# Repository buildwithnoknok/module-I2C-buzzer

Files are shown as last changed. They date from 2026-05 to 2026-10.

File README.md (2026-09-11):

# noknok Buzzer

A compact I²C‑controlled buzzer module for the noknok ecosystem.  
Designed for audio feedback, alerts, melodies, and UI interaction in modular builds.

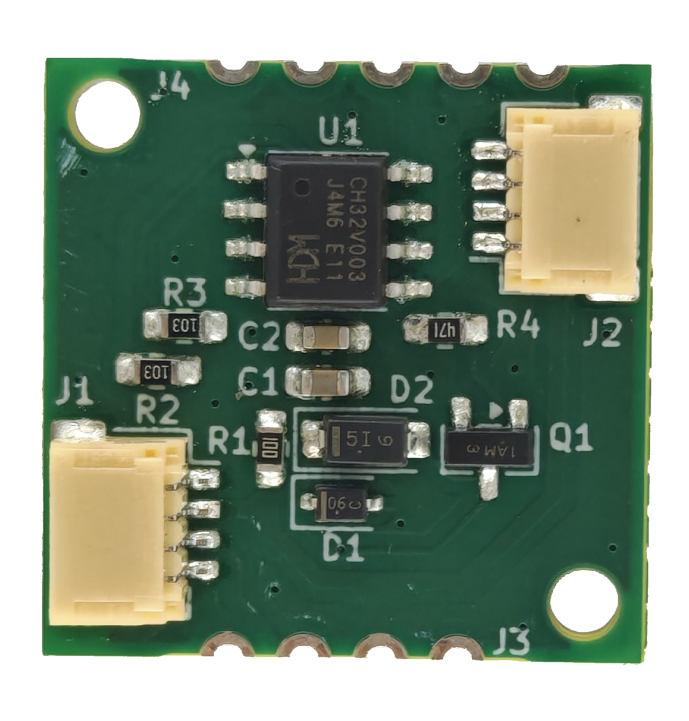
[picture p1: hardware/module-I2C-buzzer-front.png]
Buzzer Module Front

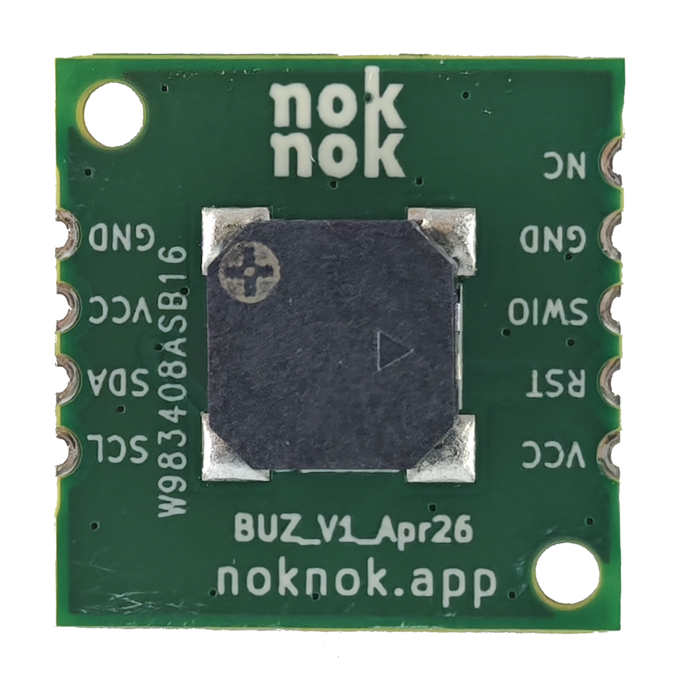
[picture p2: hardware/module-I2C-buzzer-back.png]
Buzzer Module Back


> **Visual concept:** see [`docs/noknok-buzzer-concept.md`](docs/noknok-buzzer-concept.md) for the protocol and architecture diagram (Markdown + SVG, renders right here on GitHub). A styled interactive version is in [`docs/noknok-buzzer-concept.html`](docs/noknok-buzzer-concept.html) (open in a browser).

---

## Overview

The Buzzer Module uses a **CH32V003J4M6** microcontroller to drive an **MLT‑8530** magnetic buzzer via PWM through an MMBT3904 NPN transistor. It connects to the Raspberry Pi Pico (Conductor) over the standard noknok **JST SH 4‑pin I²C connector**.

The Conductor sends a short command — a frequency, duration, and volume, or just a tune ID — and the module handles everything else independently. The Pico is free to do other things while the buzzer plays.

---

## Features

- Dynamic I²C address via noknok enumeration protocol (no hardcoded address)
- CH32V003J4M6 microcontroller (RISC‑V, 48 MHz, 16 KB flash)
- Drives MLT‑8530 magnetic buzzer via PWM
- **Fire and forget** — all timing is handled on‑module
- **Volume control** (0–100%, maps to PWM duty cycle)
- **5 preloaded tunes** stored in flash (Nokia, Happy Birthday, Beep OK/Error, Startup Chime)
- Immediate interrupt — any new command stops whatever is playing
- 3.3V operation via noknok I²C connector
- Compact 20×20 mm PCB

---

## How It Works

```
Your Python code (Pico)          JST SH 4-pin           Buzzer Module (CH32V003)
────────────────────────         ────────────           ────────────────────────
                                  GND ────────
buzzer.play(440, 2.0)  ──────►   3.3V ───────  ──────►  receives 5 bytes
                                  SDA ─ data ─          sets PWM to 440 Hz
                                  SCL ─ clk  ─          starts 2s countdown
                                                         ← ACK (Pico moves on)
                                                         ... 2 seconds pass ...
                                                         timer fires → silence
```

The Pico sends **3–5 bytes** and returns immediately. The CH32V003 handles all timing internally using a hardware timer. No blocking, no waiting.

---

## I²C Protocol

**I²C address:** assigned dynamically at boot — see [Enumeration](#enumeration).

### Commands (Pico → Buzzer)

| Bytes | Command | Description |
|---|---|---|
| `0x00` | **STOP** | Silence immediately |
| `0x01` `fH` `fL` `dur` `vol` | **PLAY NOTE** | Play a tone |
| `0x02` `id` | **PLAY TUNE** | Play a preloaded tune |
| `0xB0` | **ENTER BOOTLOADER** | Reset into the I²C bootloader for an over‑the‑wire firmware update (see [Firmware](#firmware)) |
| `0xB1` | **GET VERSION** | Standard noknok command — the next read returns 4 version bytes (see below) |

**PLAY NOTE fields:**

| Field | Size | Description |
|---|---|---|
| `fH` + `fL` | 2 bytes | Frequency in Hz, big‑endian (e.g. 440 Hz = `0x01 0xB8`) |
| `dur` | 1 byte | Duration in 100 ms units (1 = 100 ms, 10 = 1 s, 0 = play forever) |
| `vol` | 1 byte | Volume 0–100 |

### Status read (Pico ← Buzzer)

Read 1 byte from the module address:

| Value | Meaning |
|---|---|
| `0x01` | Currently playing |
| `0x00` | Idle |

### Version read (Pico ← Buzzer)

`GET_VERSION` (`0xB1`) is a **noknok ecosystem-standard** command (the `0xB0`–`0xBF` range is reserved for standard commands across every module). Write `0xB1`, then read **4 bytes**:

| Byte | Field | Meaning |
|---|---|---|
| 0 | `PROTOCOL_VERSION` | noknok protocol/API version the module speaks (`0x01`) |
| 1 | `FW_MAJOR` | Firmware major (`3`) |
| 2 | `FW_MINOR` | Firmware minor (`3`) |
| 3 | `FW_PATCH` | Firmware patch (`0`) |

Lets the Conductor compare the installed version against the version required by the product manifest. **→ Full spec:** [Ecosystem / software / readme.md §5](https://github.com/buildwithnoknok/Ecosystem/blob/main/software/readme.md#5-standard-system-commands)

---

## Preloaded Tunes

Tunes are stored as `const` arrays in the CH32V003's flash memory. Zero RAM cost.

| ID | Name | Notes |
|----|---|---|
| `0x01` | Nokia Tune | 13 notes |
| `0x02` | Happy Birthday | 28 notes |
| `0x03` | Beep OK | Rising double beep |
| `0x04` | Beep Error | Low double buzz |
| `0x05` | Startup Chime | Rising 4‑note arpeggio (plays on every boot) |

---

## Enumeration

The module uses the standard noknok dynamic enumeration protocol — no hardcoded I²C address. At boot it plays the startup chime while counting a UID-derived backoff delay, then joins the bus at `0x7F` for address assignment by the Conductor.

**→ Full protocol spec:** [Ecosystem / software / enumeration.md](https://github.com/buildwithnoknok/Ecosystem/blob/main/software/enumeration.md)

---

## Python API

Use the `noknok.py` library from the [Ecosystem repo](https://github.com/buildwithnoknok/brain-Pico/tree/main/software) on the Pico.

```python
from noknok import Conductor

c = Conductor()        # GP8 = SDA, GP9 = SCL
c.enumerate()          # discover all modules (takes ~3 s)

# Single note — fire and forget
c.buzzer[0].play(440, 2000)             # 440 Hz for 2 seconds
c.buzzer[0].play(440, 1000, volume=50)  # half volume

# Predefined tune — fire and forget
c.buzzer[0].tune(c.buzzer[0].NOKIA)
c.buzzer[0].tune(c.buzzer[0].HAPPY_BIRTHDAY)
c.buzzer[0].tune(c.buzzer[0].BEEP_OK)

# Note in a melody — plays and waits
c.buzzer[0].note(440, 500)   # plays 440 Hz for 500 ms, then returns

# Stop
c.buzzer[0].stop()

# Status
c.buzzer[0].is_playing()     # True or False
c.buzzer[0].wait()           # block until idle

# Multiple buzzers
c.buzzer[1].play(880, 500)   # second buzzer (if present)
```

---

## Files on the Pico

These are **Conductor-level files shared by every module** - not buzzer-specific:

| File | Purpose |
|---|---|
| `noknok.py` | noknok Conductor library - master copy in [brain-Pico/software](https://github.com/buildwithnoknok/brain-Pico/tree/main/software) |
| `noknok_state.json` | Module address persistence, auto-created by `enumerate()` - see [enumeration.md](https://github.com/buildwithnoknok/Ecosystem/blob/main/software/enumeration.md) |
| `noknok_roles.json` | Role -> UID mapping - see [roles.md](https://github.com/buildwithnoknok/Ecosystem/blob/main/software/roles.md) |

> **Filesystem write access required.** See the [CircuitPython filesystem docs](https://docs.circuitpython.org/en/latest/docs/library/storage.html).

---

## Hardware

| Spec | Value |
|---|---|
| PCB size | 20 × 20 mm |
| MCU | CH32V003J4M6 (SOP‑8, RISC‑V, 48 MHz) |
| Buzzer | MLT‑8530 (magnetic, 3.3V) |
| Driver | MMBT3904 NPN transistor |
| Connector | JST SH 4‑pin (Qwiic / STEMMA QT compatible) |
| Supply voltage | 3.3V via I²C connector |
| PWM pin | PA1 (TIM1 CH2) |
| I²C SDA | PC1 |
| I²C SCL | PC2 |
| Flash header | J3 — 3-pad pogo (GND, SWIO, VCC), noknok M2.5-keyed footprint. SWIO/PD1 also carries the status LED (D3, active LOW). |
| Hardware version | v2.0 |

---

## Firmware

**v3.5.0 runs under the shared noknok I²C bootloader** ([module-I2C-bootloader](https://github.com/buildwithnoknok/module-I2C-bootloader)) — the module can be re‑flashed **over the I²C bus** (no SWDIO cable in the field). The application is linked at the `0x1400` offset (`app.ld`) above the 5 KB stage-0 + stage-1 bootloader (layout 2) and reserves the top 16 B of RAM for the bootloader handoff cell. Command `0xB0` drops the running module into the bootloader for an update.

```bash
cd firmware/src
make build   # compile the offset-linked application -> buzzer_firmware.bin
```

Flashing: normally over I²C from the Pico (`module_flasher.py` in `brain-Pico`). A blank board needs the bootloader SWD‑flashed once first. SWD remains the unbrickable backstop — see *Recovery & SWD flashing* in the [bootloader README](https://github.com/buildwithnoknok/module-I2C-bootloader#recovery--swd-flashing). `make flash` here still does a one‑off SWD flash of the app for bench bring‑up.

> ch32fun must be installed at `../ch32fun/` relative to `firmware/src/` — see [cnlohr/ch32v003fun](https://github.com/cnlohr/ch32v003fun) for setup instructions.

| Metric | Value |
|---|---|
| Firmware version | v3.5.0 (bootloader‑hosted) |
| Application size | 2928 B of 11 KB app region (26%) |
| RAM used | 76 B of ~2 KB (4%) |

### Files

| File | Description |
|---|---|
| `firmware/src/buzzer_firmware.c` | CH32V003 firmware source |
| `firmware/src/Makefile` | Build configuration |
| `firmware/src/funconfig.h` | ch32v003fun config |
| `firmware/src/app.ld` | Linker script (application at 0x1400, above the 1 KB stage-0 + 4 KB stage-1) |
| `firmware/bin/buzzer_firmware.bin` | Compiled application binary |
| `docs/noknok-buzzer-concept.md` | Concept diagram - Markdown + SVG (renders on GitHub) |
| `docs/noknok-buzzer-concept.html` | Same concept as a styled interactive page (browser) |

---

## Changelog

### v3.5.0 — app base 0x1400 (bootloader layout 2)
Relinked at the `0x1400` flash offset (bootloader **layout 2**: 1 KB stage-0 + 4 KB stage-1 below the app; was `0x1000`). Firmware behaviour unchanged. **Not compatible with the legacy monolithic bootloader or a layout-1 stage-1** — such a module gets stage-0 + stage-1 v1.1.0 over SWD first, then this app over I²C. See [module-I2C-bootloader](https://github.com/buildwithnoknok/module-I2C-bootloader).

### v3.4.0 — watchdog + boot-health handshake (DEV-31)
Runs the independent watchdog (~2 s, kicked every main-loop pass) and writes `0` to `0x200007F8` the moment its I²C address is assigned — the app-health handshake with the stage-1 bootloader. Stage-1 counts watchdog resets and parks the module (error 7, rescued by the Conductor by UID) after three in a row, instead of booting a broken app forever. Contract: [Ecosystem / software / bootloader-update.md §3](https://github.com/buildwithnoknok/Ecosystem/blob/main/software/bootloader-update.md). No protocol or command change.

### v3.3.1 and earlier
See the git history.

## Status

| Area | Status |
|---|---|
| Hardware | v2.0 complete |
| Firmware | **v3.5.0 — complete (bootloader‑hosted, I²C OTA)** |
| Python library | **complete** (in [Ecosystem repo](https://github.com/buildwithnoknok/brain-Pico/tree/main/software)) |
| Documentation | **complete** |

---

## License

- Firmware / code: MIT — see [LICENSE](LICENSE).
- Hardware (schematics, PCB layout, fab files): CC BY-SA 4.0 — see [LICENSE-hardware](LICENSE-hardware).

## Trademarks

**noknok** is a registered trademark in Switzerland (Swissreg 1300007033).

Qwiic is a registered trademark of SparkFun Electronics, Inc. STEMMA QT is a
trademark of Adafruit Industries, LLC. Both are named here only to state
connector compatibility - noknok is not affiliated with, endorsed by, or
sponsored by either company.
---

---

## Safety & Liability

noknok hardware is an electronic device and a DIY/maker kit. You assemble, modify, flash, power, and operate it at your own risk, and it is provided as is, without warranty. See the full notice: [License, Safety & Liability](https://buildwithnoknok.github.io/safety-and-license/).

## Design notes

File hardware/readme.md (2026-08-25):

# Hardware — noknok Buzzer

Hardware design files for the noknok Buzzer module (CH32V003J4M6 — I2C-controlled magnetic buzzer).

- KiCad project: `kicad/module-I2C-buzzer.*`
- Schematic (PDF): `module-I2C-buzzer-Schematics.pdf`
- BOM: `module-I2C-buzzer_BOM.xls`
- Board renders: `module-I2C-buzzer-front.png`, `module-I2C-buzzer-back.png` *(pre-V2 renders — pending re-export)*

Hardware is licensed CC BY-SA 4.0 (see `../LICENSE-hardware`). Connector, flashing and mounting standards follow the [noknok Ecosystem guidelines](https://github.com/buildwithnoknok/Ecosystem) (electrical + mechanical).

---

## Hardware Change Record

### v2.0 — changes from v1.0
- **Fixed R1 (VDD series) to 1 Ω** — this was previously a documented-but-unfixed known issue: the schematic still shipped with the default 10 Ω, which caused a brownout reset when the buzzer fired at high volume (the beep current spike through 10 Ω trips BOR). V1 units needed a manual bodge; V2 corrects it in the schematic itself. This is a buzzer-specific deviation — knob and LED Button stay at the 10 Ω default (no spiky VDD load).
- **Status indicator LED on PD1** (in parallel with the SWIO flashing line — zero extra GPIO). Active-low: `+3V3_PROT → R2 (2.2 kΩ) → D3 anode; D3 cathode → PD1/SWIO`. Driven by the bootloader (off = app running, slow pulse = updating/recovering, solid = error). Parts: red 0603 LED (LCSC C2286) + 2.2 kΩ 0603 (LCSC C4190).
- **Removed both castellated edge pads** — the 5-pin flashing edge (old J4) and the redundant I2C edge (old J3). I2C is via the JST-SH (Qwiic) connectors J1/J2 only.
- **New flashing interface (J3)** — noknok flash pads (`noknok_FlashPads_I2C-module_1x3_M2.5`): 3 single-side SMD pogo pads (GND / SWIO / VCC) plus an embedded M2.5 keyed mounting hole, from the noknok KiCad library in the Ecosystem repo. Pad row is offset toward the keyed hole (not centered) so a 180°-flipped clamp contact can't seat and reverse-power the board.
- **Second mounting hole (H1)** — plain `noknok_MountingHole_2.5mm_M2.5`, diagonally opposite the flash-pad hole.
- **Removed the on-board I²C pull-up resistors** (previously R2/R3) — pull-ups now live on the host (Conductor), not per module (avoids stacking on the shared bus). The host must provide the bus pull-ups (proposed 3.3 kΩ); a noknok pull-up PCB covers third-party hosts that lack them. See the [I²C Pull-up Resistor Strategy ADR](https://noknokdev.atlassian.net/wiki/spaces/SD/pages/82280449). *(`R2` is reused above for the new status-LED resistor — it is not the old pull-up.)*
- **Buzzer drive resistor renumbered R4 → R3** (still 470 Ω, unchanged value) — a side effect of the old pull-ups' designators being freed up.
- D1 (protection Zener) and D2 (1N4148W) are unchanged from v1.0.

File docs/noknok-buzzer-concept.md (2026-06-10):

# noknok Buzzer - Module Concept

> Conductor (Pico)  <->  Musician (CH32V003)  /  I2C over JST SH 4-pin

A GitHub-readable version of the concept diagram. For the styled interactive page, open
[`noknok-buzzer-concept.html`](noknok-buzzer-concept.html) in a browser.

Buzzer concept diagram

---

## The idea

The Conductor (Raspberry Pi Pico) sends a short command over I2C; the Musician (the
buzzer''s CH32V003) does everything else. The Pico **moves on instantly** - all timing
happens on the module.

---

## Conductor side (Pico) - what you write

```python
# Single note - fire and forget
buzzer.play(440, duration=2.0)
buzzer.play(440, duration=2.0, volume=75)

# Predefined tune - also fire and forget
buzzer.play("nokia-tune")
buzzer.play("happy-birthday")
buzzer.play("beep-ok")

# Stop at any time
buzzer.stop()
```

> This is the conceptual API. The actual library calls are `c.buzzer[0].play(440, 2000)`
> and `c.buzzer[0].tune(...)` - see the module [README](../README.md).

## What goes over I2C

**Play a single note - 5 bytes** (example: 440 Hz, 2.0 s, 100% volume):

| Byte | `0x01` | `0x01` | `0xB8` | `0x14` | `0x64` |
|---|---|---|---|---|---|
| Meaning | CMD PLAY NOTE | FREQ high | FREQ low | DUR (x100 ms) | VOL (0-100) |

**Play a predefined tune - 2 bytes** (example: "nokia-tune", ID `0x01`):

| Byte | `0x02` | `0x01` |
|---|---|---|
| Meaning | CMD PLAY TUNE | TUNE ID |

**Stop - 1 byte:**

| Byte | `0x00` |
|---|---|
| Meaning | CMD STOP (immediate, whatever is playing) |

## The I2C bus (JST SH 4-pin)

| Wire | Purpose |
|---|---|
| GND | Ground |
| 3.3V | Power |
| SDA | Data |
| SCL | Clock |

- Pico to buzzer: commands and data
- Buzzer to Pico: status reply (1 byte) - `0x01` = playing, `0x00` = idle

---

## Musician side (CH32V003) - what the firmware does

| Command | Action |
|---|---|
| `0x00` STOP | Stop PWM immediately, clear the busy flag. |
| `0x01` PLAY NOTE | Read freq (2 bytes), duration, volume; set the PWM prescaler and duty cycle; start the timer; return to I2C immediately - the timer runs in the background. |
| `0x02` PLAY TUNE | Read the tune ID; look up the note sequence in flash; play each note then silence; return to I2C immediately - the tune runs in the background. |
| READ | Reply with 1 byte: `0x01` = playing, `0x00` = idle. |

### Tune library - stored in CH32V003 flash (read-only)

| ID | Tune | Notes |
|----|---|---|
| `0x01` | Nokia Tune | 13 notes |
| `0x02` | Happy Birthday | 25 notes |
| `0x03` | Beep - OK | 2 notes |
| `0x04` | Beep - Error | 2 notes |
| `0x05` | Startup Chime | 4 notes |
| `0x06+` | Reserved for future tunes | - |

Each tune is an array of `{freq, duration_ms}` pairs, stored as `const` in C and compiled
into flash. Zero RAM cost.

---

## Why it is designed this way

**Why fire and forget?** The Pico sends a command and moves on instantly. The CH32V003
handles all timing with its hardware timer, so the Pico never has to wait or count
milliseconds - it is free to do other things while the buzzer plays.

**Why tunes on the CH32V003?** Tunes are always available, no matter what app is on the
Pico. The Pico sends 2 bytes; the CH32V003 knows the rest. Adding a tune means updating
the buzzer firmware, independent of any Pico app.

**Memory usage.** The CH32V003 has 16 KB flash. A 25-note tune costs ~100 bytes; ten
tunes ~1 KB; firmware logic ~3-4 KB - plenty of room for the register header and the
[I2C OTA bootloader](https://github.com/buildwithnoknok/module-I2C-bootloader) too.

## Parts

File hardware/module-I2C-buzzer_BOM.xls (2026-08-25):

Item # | *Designator | *Qty | Manufacturer | *Mfg Part # | Description / Value | LCSC Part # | *Package/Footprint | Substitute
1 | BUZZER1 | 1 | Huaneng | MLT-8530 | MLT-8530 | C94599 | BUZ-SMD_4P-L8.5-W8.5-P8.50-BR
2 | C1 | 1 | SAMSUNG | CL10A106KP8NNNC | 10uF | C19702 | C_0603_1608Metric_Pad1.08x0.95mm_HandSolder
3 | C2 | 1 | SAMSUNG | CL10B104KA8NNNC | 0.1uF | C1590 | C_0603_1608Metric_Pad1.08x0.95mm_HandSolder
4 | D1 | 1 | onsemi | MM3Z3V6T1G | D_Zener | C116949 | D_SOD-323 | ROHM『 』UDZVTE-173.6B『 』C209558
5 | D2 | 1 | onsemi | MMSD4148T1G | 1N4148 | C11177 | D_SOD-123
6 | D3 | 1 | Hubei KENTO Elec | KT-0603R | LED RED WATER CLEAR 0603 SMD | C2286 | 0603
7 | J1, J2 | 2 | JST | SM04B-SRSS-TB(LF)(SN) | JST 4 Pin Qwiic I2C Connector | C160404 | JST_SH_SM04B-SRSS-TB_1x04-1MP_P1.00mm_Horizontal
8 | Q1 | 1 | onsemi | MMBT3904LT1G | MMBT3904 | C81464 | SOT-23
9 | R1 | 1 | YAGEO | RC0603JR-071RL | 1R | C127987 | R_0603_1608Metric | Viking『 』ARG03FTC0010『 』C2902646
10 | R2 | 1 | YAGEO | RC0603JR-072K2L | 2.2k | C113303 | R_0603_1608Metric | Viking『 』ARG03FTC2201『 』C217937
11 | R3 | 1 | YAGEO | RC0603JR-07470RL | 470R | C114433 | R_0603_1608Metric_Pad0.98x0.95mm_HandSolder | Viking『 』ARG03FTC4700『 』TBD
12 | U1 | 1 | WCH | CH32V003J4M6 | CH32V003J4M6 | C5346354 | JEITA_SOIC-8_3.9x4.9mm_P1.27mm

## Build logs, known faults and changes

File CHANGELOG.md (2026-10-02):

# Changelog - noknok Buzzer module firmware

Newest first. One entry per version bump, written in the same commit as the bump. Format:
`## <version> - <date>` then `- DEV-xx - what changed and why. Breaking: yes/no.`
Convention: Confluence "Development Conventions" (SD space, page 120160257).

## Baseline - 2026-10-02

- Changelog starts here. Current: buzzer firmware 3.5.0 (released 2026-09-11). Earlier history: git log and the README.

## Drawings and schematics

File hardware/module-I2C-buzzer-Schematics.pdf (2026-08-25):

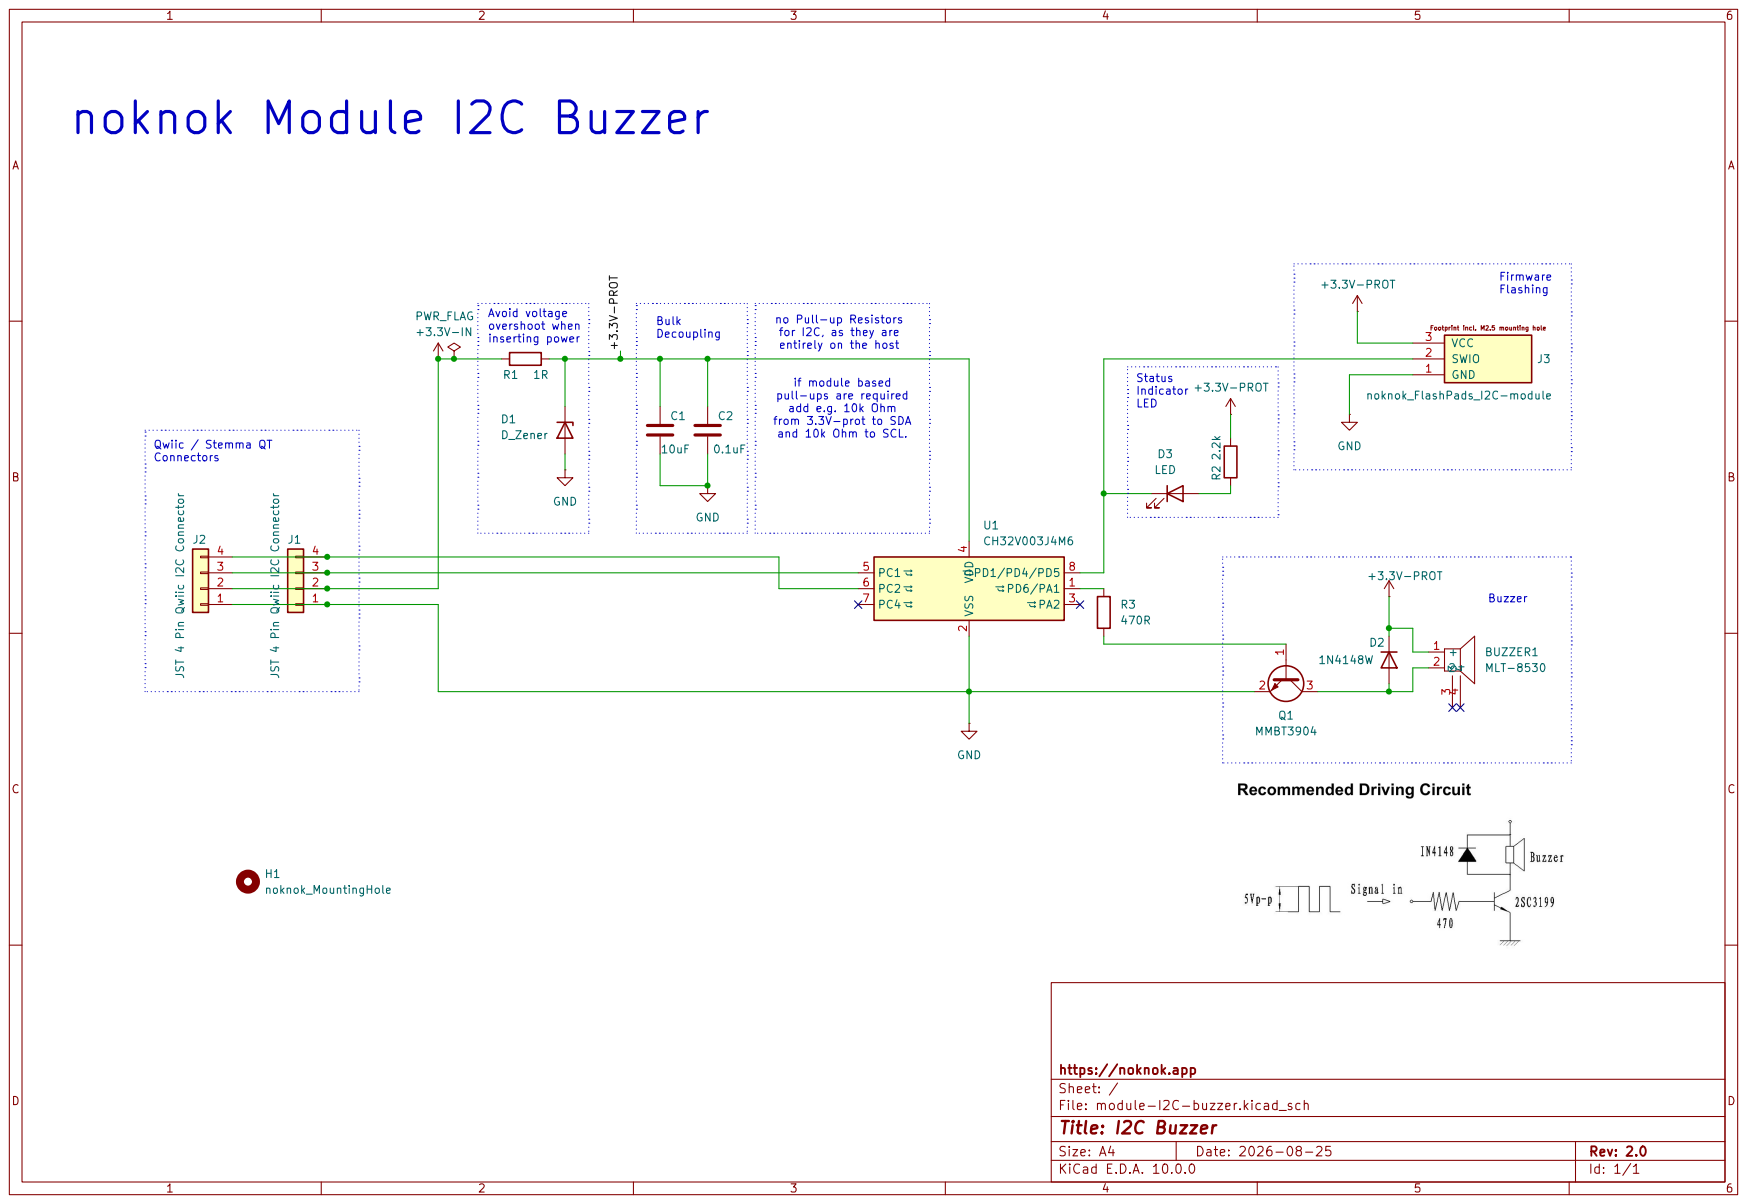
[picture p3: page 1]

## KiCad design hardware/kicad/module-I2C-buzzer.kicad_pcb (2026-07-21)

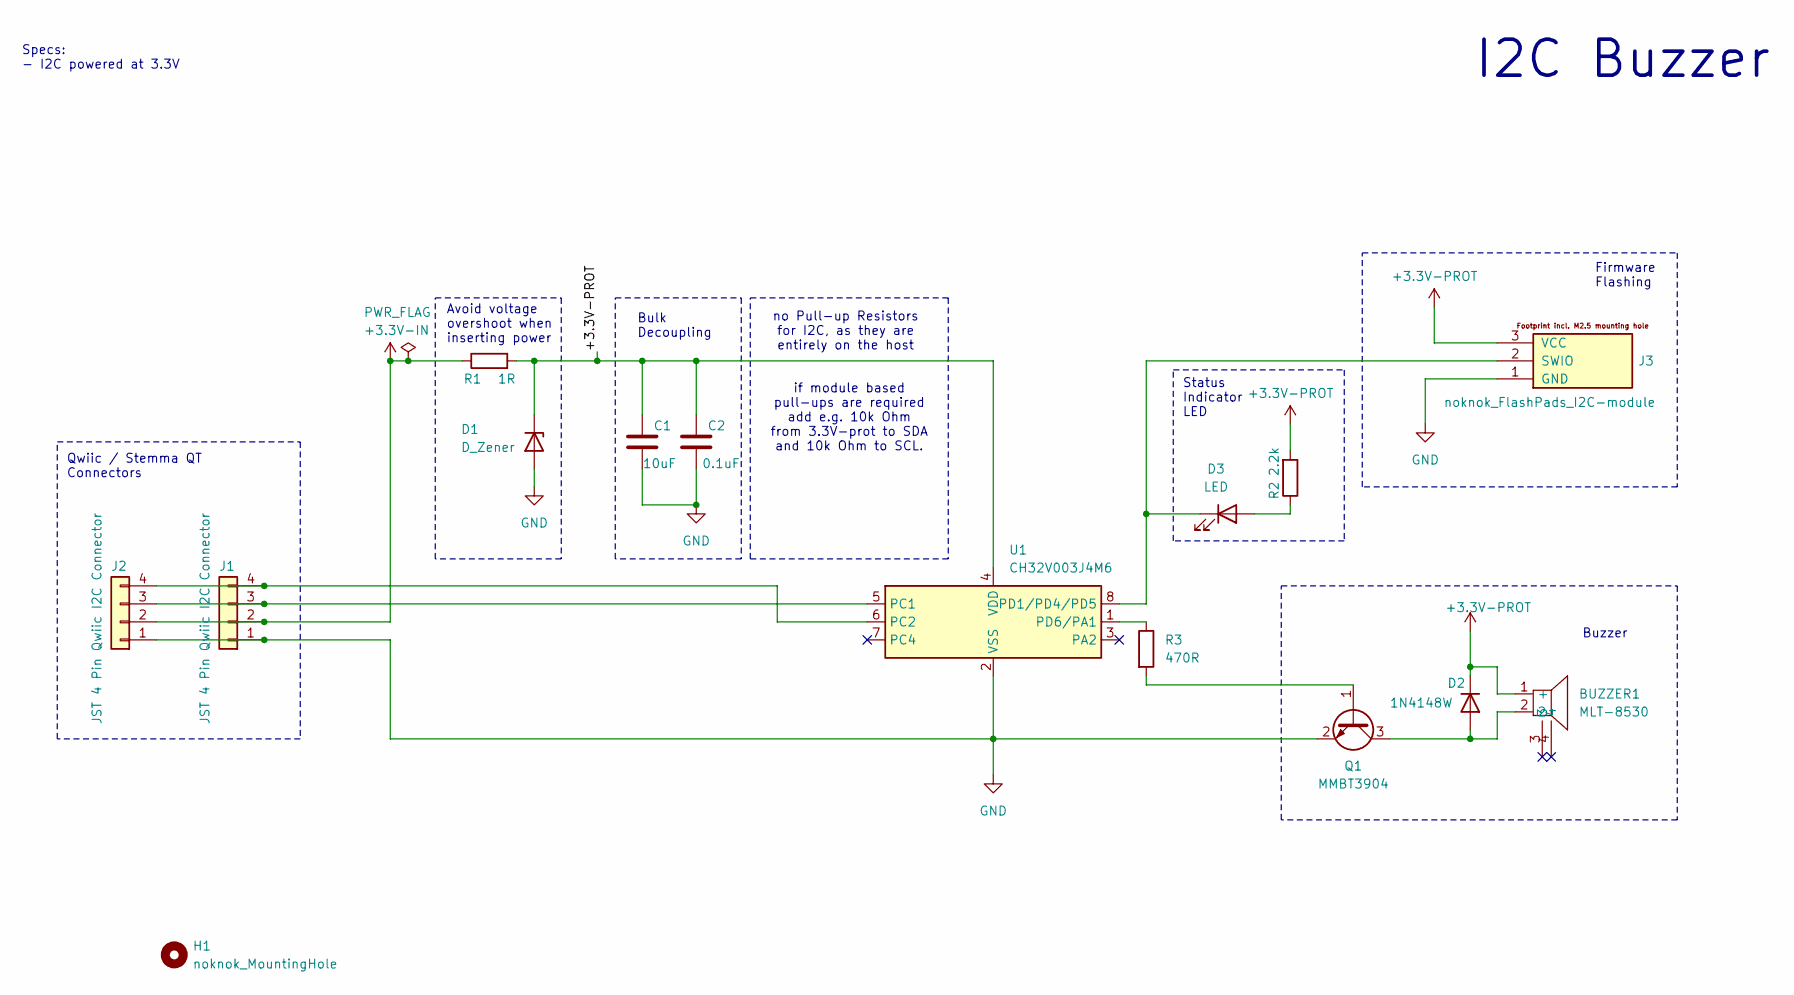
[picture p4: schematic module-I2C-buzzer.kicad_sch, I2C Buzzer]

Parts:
BUZZER1: MLT-8530; BUZ-SMD_4P-L8.5-W8.5-P8.50-BR; LCSC Part C94599
C1: 10uF; C_0603_1608Metric_Pad1.08x0.95mm_HandSolder
C2: 0.1uF; C_0603_1608Metric_Pad1.08x0.95mm_HandSolder
D1: D_Zener; D_SOD-323
D2: 1N4148W; D_SOD-123
D3: LED; LED_0603_1608Metric
H1: noknok_MountingHole; noknok_MountingHole_2.5mm_M2.5
J1, J2: JST 4 Pin Qwiic I2C Connector; JST_SH_SM04B-SRSS-TB_1x04-1MP_P1.00mm_Horizontal
J3: noknok_FlashPads_I2C-module; noknok_FlashPads_I2C-module_1x3_M2.5
Q1: MMBT3904; SOT-23
R1: 1R; R_0603_1608Metric
R2: 2.2k; R_0603_1608Metric
R3: 470R; R_0603_1608Metric_Pad0.98x0.95mm_HandSolder
U1: CH32V003J4M6; JEITA_SOIC-8_3.9x4.9mm_P1.27mm

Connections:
+3.3V-IN: J1.2, J2.2, R1.1
+3.3V-PROT: BUZZER1.1 (+), C1.1, C2.1, D1.1 (K), D2.1 (K), J3.3 (VCC), R1.2, R2.2, U1.4 (VDD)
GND: C1.2, C2.2, D1.2 (A), J1.1, J2.1, J3.1 (GND), Q1.2 (E), U1.2 (VSS)
unnamed: BUZZER1.2, D2.2 (A), Q1.3 (C)
unnamed: D3.2 (A), R2.1
unnamed: D3.1 (K), J3.2 (SWIO), U1.8 (PD1/PD4/PD5)
unnamed: J1.3, J2.3, U1.5 (PC1)
unnamed: J1.4, J2.4, U1.6 (PC2)
unnamed: Q1.1 (B), R3.2
unnamed: R3.1, U1.1 (PD6/PA1)

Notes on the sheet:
Specs: - I2C powered at 3.3V
Avoid voltage overshoot when inserting power
I2C Buzzer
no Pull-up Resistors for I2C, as they are entirely on the host
if module based pull-ups are required add e.g. 10k Ohm from 3.3V-prot to SDA and 10k Ohm to SCL.
Firmware Flashing
Buzzer
Status Indicator LED
Qwiic / Stemma QT Connectors
Bulk Decoupling

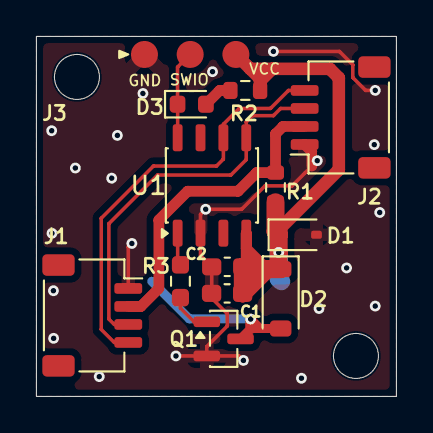
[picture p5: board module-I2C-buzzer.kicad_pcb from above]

Board: 2 copper layers, 20.0 x 20.0 mm, 15 parts (1 on the bottom side), 10 nets.

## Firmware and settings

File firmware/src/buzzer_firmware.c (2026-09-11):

/*
 * noknok Buzzer Module Firmware  v3.4.0
 *
 * v3.4.0: DEV-31 hardening C — independent watchdog + boot-attempt handshake
 *   with stage-1 (clears the counter once an I2C address is assigned).
 * CH32V003J4M6 (SOP-8)  |  Stack: cnlohr/ch32fun
 *
 * ── What changed from v2 ────────────────────────────────────────────────
 *   v2 had a hardcoded I2C address (0x45).
 *   v3 adds dynamic address discovery (enumeration):
 *   - All modules boot with I2C OFF, counting a UID-seeded backoff timer.
 *   - When the timer fires, I2C turns on at the staging address (0x7F).
 *   - The Conductor reads the 10-byte UID+type+CRC response.
 *   - The Conductor writes a new unique address. Module switches and is ready.
 *   This allows multiple identical modules on the same bus.
 *
 * ── Hardware ─────────────────────────────────────────────────────────────
 *   PA1 (pin 2)  TIM1 CH2 → MMBT3904 NPN → MLT-8530 buzzer
 *   PC1 (pin 3)  I2C SDA
 *   PC2          I2C SCL
 *
 * ── Enumeration protocol ─────────────────────────────────────────────────
 *   Staging address : 0x7F
 *   Runtime address : assigned by Conductor (0x08–0x77)
 *
 *   1. Conductor reads 10 bytes from 0x7F:
 *        [UID 0..7]   64-bit hardware UID (little-endian)
 *        [0x01]       MODULE_TYPE (buzzer)
 *        [CRC8]       CRC8 of bytes 0–8
 *
 *   2. Conductor writes to 0x7F:
 *        [0x1D, new_addr]   ASSIGN — module switches to new_addr
 *
 * ── Normal operation protocol ────────────────────────────────────────────
 *   I2C address: assigned at runtime
 *
 *   Pico WRITES:
 *     [0x00]                     STOP
 *     [0x01, fH, fL, dur, vol]   PLAY NOTE
 *     [0x02, id]                 PLAY TUNE (1–5)
 *     [0xB0]                     ENTER BOOTLOADER (I2C OTA update)
 *     [0xB1]                     GET VERSION — next read returns 4 version bytes
 *
 *   Pico READS:
 *     1 byte: 0x01=playing, 0x00=idle          (default)
 *     4 bytes after 0xB1: [PROTOCOL_VER, FW_MAJOR, FW_MINOR, FW_PATCH]
 *
 *   GET_VERSION (0xB1) is a noknok ecosystem-standard command (range
 *   0xB0–0xBF reserved). See Ecosystem/software/readme.md §5.
 */

#include "ch32fun.h"
#include <stdint.h>

/* ═══════════════════════════════════════════════════════════════════════════
 * CONFIGURATION
 * ═══════════════════════════════════════════════════════════════════════════ */

#define ENUM_ADDR       0x7F    /* staging address — all modules start here */
#define MODULE_TYPE     0x01    /* 0x01 = buzzer */
#define TIM_CLK_HZ      1000000UL

#define CMD_STOP        0x00
#define CMD_PLAY_NOTE   0x01
#define CMD_PLAY_TUNE   0x02
#define CMD_ENTER_BOOTLOADER 0xB0   /* reset into the I2C bootloader for OTA update */
#define CMD_GET_VERSION 0xB1        /* report [PROTOCOL_VERSION, FW_MAJOR, FW_MINOR, FW_PATCH] */
#define REG_ASSIGN_ADDR 0x1D

/* ── Version reporting (noknok standard command, DEV-1) ──────────────────────
 * PROTOCOL_VERSION = which noknok protocol/API this module speaks — NOT the
 * firmware version. Bumped only when the shared protocol changes. The
 * FW_VERSION_* triple is this module's firmware semver; keep it equal to the
 * release tag. Reported on a GET_VERSION (0xB1) read.
 *
 * v3.3.1 (DEV-6): version-only bump, NO functional change — exists purely to
 *   create an installed-vs-required version delta so the OTA auto-update path
 *   can be rehearsed end-to-end (3.3.0 buzzers see "update available" → flash). */
#define PROTOCOL_VERSION 0x01
#define FW_VERSION_MAJOR 3
#define FW_VERSION_MINOR 5
#define FW_VERSION_PATCH 0

/* Bootloader handoff cell — top 16 B of RAM, reserved by app.ld (stack ends
 * below it). Writing this magic then warm-resetting drops the module into the
 * shared noknok I2C bootloader (flash mode at 0x7E). SRAM survives a warm reset.
 * Magic + address MUST match noknok_bootloader. */
#define BL_MAGIC_CELL   (*(volatile uint32_t *)0x200007F0U)
#define BL_MAGIC_ENTER  0x6E6B4231U   /* "nkB1" */

/* ── App health handshake with stage-1 (DEV-31 hardening C) ──────────────────
 * Stage-1 counts every boot of this app in a no-init RAM cell and stops booting
 * it after three consecutive warm resets without the app ever proving itself,
 * parking the module in the bootloader at 0x7E so the host can push a good
 * image instead. That turns "a broken app with a valid CRC is booted forever"
 * into "a broken app gets three tries". Two things make it work here:
 *   - the independent watchdog, so a hang becomes a warm reset (~2 s), and
 *   - clearing the counter the moment we KNOW we are healthy: an I2C address
 *     has been assigned, i.e. enumeration completed, i.e. I2C works.
 * Address and tag must match noknok_stage1. */
#define BOOT_ATTEMPT_CELL (*(volatile uint32_t *)0x200007F8U)

static void iwdg_init(void)
{
    /* LSI ~128 kHz / 64 = 2 kHz; reload 4095 -> ~2.05 s. Hardware starts LSI. */
    IWDG->CTLR = 0x5555;  IWDG->PSCR = 4;
    IWDG->CTLR = 0x5555;  IWDG->RLDR = 0xFFF;
    IWDG->CTLR = 0xCCCC;  /* start — cannot be stopped except by reset */
}
static inline void iwdg_kick(void) { IWDG->CTLR = 0xAAAA; }

/* CH32V003 64-bit hardware UID (ESIG_UNIID1 + ESIG_UNIID2 = 8 bytes) */
#define UID_ADDR        ((volatile uint8_t*)0x1FFFF7E8)
#define UID_LEN         8


/* ═══════════════════════════════════════════════════════════════════════════
 * TUNE DATA  (stored in flash, zero RAM cost)
 * ═══════════════════════════════════════════════════════════════════════════ */

typedef struct { uint16_t freq; uint16_t dur_ms; } Note;

#define N_REST  0
#define N_C4    262
#define N_Cs4   277
#define N_D4    294
#define N_Ds4   311
#define N_E4    330
#define N_F4    349
#define N_Fs4   370
#define N_G4    392
#define N_Gs4   415
#define N_A4    440
#define N_Bb4   466
#define N_B4    494
#define N_C5    523
#define N_Cs5   554
#define N_D5    587
#define N_E5    659
#define N_G5    784
#define N_A5    880
#define N_C6    1047

static const Note tune_nokia[] = {
    {N_E5,125},{N_D5,125},{N_Fs4,250},{N_Gs4,250},
    {N_Cs5,125},{N_B4,125},{N_D4,250},{N_E4,250},
    {N_B4,125},{N_A4,125},{N_Cs4,250},{N_E4,250},
    {N_A4,500},
};
static const Note tune_happy_birthday[] = {
    {N_C4,200},{N_C4,200},{N_D4,400},{N_C4,400},{N_F4,400},{N_E4,800},{N_REST,200},
    {N_C4,200},{N_C4,200},{N_D4,400},{N_C4,400},{N_G4,400},{N_C5,800},{N_REST,200},
    {N_C4,200},{N_C4,200},{N_C5,400},{N_A4,400},{N_F4,200},{N_E4,200},{N_D4,800},{N_REST,200},
    {N_Bb4,200},{N_Bb4,200},{N_A4,400},{N_F4,400},{N_G4,400},{N_F4,800},
};
static const Note tune_beep_ok[]    = {{N_A4,80},{N_REST,40},{N_C5,80}};
static const Note tune_beep_error[] = {{N_D4,150},{N_REST,60},{N_D4,150}};
static const Note tune_startup[]    = {{N_C5,100},{N_E5,100},{N_G5,100},{N_C6,250}};

typedef struct { const Note *notes; uint8_t count; } Tune;
#define TUNE_COUNT 5
static const Tune tune_table[TUNE_COUNT + 1] = {
    {0,0},
    {tune_nokia,          sizeof(tune_nokia)          / sizeof(Note)},
    {tune_happy_birthday, sizeof(tune_happy_birthday) / sizeof(Note)},
    {tune_beep_ok,        sizeof(tune_beep_ok)        / sizeof(Note)},
    {tune_beep_error,     sizeof(tune_beep_error)     / sizeof(Note)},
    {tune_startup,        sizeof(tune_startup)        / sizeof(Note)},
};


/* ═══════════════════════════════════════════════════════════════════════════
 * STATE
 * ═══════════════════════════════════════════════════════════════════════════ */

typedef enum {
    DEV_BOOT_WAITING,   /* I2C off, counting backoff timer */
    DEV_ENUM_READY,     /* I2C on at 0x7F, waiting for Conductor */
    DEV_ASSIGNING,      /* got new address, switch pending (done in main loop) */
    DEV_ASSIGNED,       /* normal operation at assigned address */
} DeviceState;

typedef enum { PLAY_IDLE, PLAY_NOTE, PLAY_TUNE } PlayState;

static volatile DeviceState dev_state  = DEV_BOOT_WAITING;
static volatile PlayState   play_state = PLAY_IDLE;
static volatile uint32_t    ms_tick    = 0;
static volatile uint8_t     new_addr   = 0;  /* set in ISR, used in main loop */
static volatile uint8_t     version_pending = 0; /* set in ISR on 0xB1; next read returns version */

/* Playback */
static volatile uint32_t    note_start_ms = 0;
static volatile uint32_t    note_dur_ms   = 0;
static volatile const Note *tune_notes    = 0;
static volatile uint8_t     tune_len      = 0;
static volatile uint8_t     tune_idx      = 0;
static volatile uint32_t    tune_note_start_ms = 0;

/* I2C receive */
#define RX_BUF_SIZE 8
static volatile uint8_t rx_buf[RX_BUF_SIZE];
static volatile uint8_t rx_len    = 0;
static volatile uint8_t cmd_ready = 0;

/* I2C transmit (8 UID + 1 type + 1 CRC = 10 bytes) */
#define TX_BUF_SIZE 10
static volatile uint8_t tx_buf[TX_BUF_SIZE];
static volatile uint8_t tx_len = 0;
static volatile uint8_t tx_idx = 0;


/* ═══════════════════════════════════════════════════════════════════════════
 * CRC8  (polynomial 0x07)
 * ═══════════════════════════════════════════════════════════════════════════ */

static uint8_t crc8(const uint8_t *data, uint8_t len)
{
    uint8_t crc = 0x00;
    for (uint8_t i = 0; i < len; i++) {
        crc ^= data[i];
        for (uint8_t j = 0; j < 8; j++)
            crc = (crc & 0x80) ? (crc << 1) ^ 0x07 : (crc << 1);
    }
    return crc;
}


/* ═══════════════════════════════════════════════════════════════════════════
 * BACKOFF TIMER  —  proper FNV-1a hash of 8 UID bytes
 *
 * Bug fix v3.1: previous version computed h = seed XOR 2166136261 as the
 * starting value. When seed == 2166136261 (the FNV offset basis), this
 * gave h = 0, nullifying the offset and causing chips from the same batch
 * to produce near-identical backoff times (10 ms apart → collision).
 *
 * Fix: calc_backoff() now starts with h = 2166136261 (the FNV-1a offset)
 * directly, without XOR. This is correct FNV-1a and spreads same-batch
 * chips reliably across the full 300–2799 ms range.
 *
 * Re-backoff on collision uses ms_tick as seed and a shorter range (50–549ms)
 * so the Conductor doesn't have to wait long for retry.
 * ═══════════════════════════════════════════════════════════════════════════ */

static uint32_t backoff_ms;
static uint32_t enum_ready_start_ms = 0;

/* Standard FNV-1a hash over 8 UID bytes starting from given h value */
static uint32_t fnv_hash(uint32_t h)
{
    volatile uint8_t *uid = UID_ADDR;
    for (uint8_t i = 0; i < UID_LEN; i++) {
        h ^= uid[i];
        h *= 16777619UL;
    }
    return h;
}

/* Initial backoff: proper FNV-1a, range 300–2799 ms */
static void calc_backoff(void)
{
    backoff_ms = (fnv_hash(2166136261UL) % 2500) + 300;
}

/* Re-backoff after collision: seed with ms_tick, short range 50–549 ms */
static uint32_t calc_rebackoff_ms(void)
{
    return ms_tick + (fnv_hash(ms_tick) % 500) + 50;
}


/* ═══════════════════════════════════════════════════════════════════════════
 * BUILD UID RESPONSE  —  10 bytes: [UID 8 bytes] + [MODULE_TYPE] + [CRC8]
 * ═══════════════════════════════════════════════════════════════════════════ */

static void build_uid_response(void)
{
    volatile uint8_t *uid = UID_ADDR;
    for (uint8_t i = 0; i < UID_LEN; i++)
        tx_buf[i] = uid[i];
    tx_buf[8] = MODULE_TYPE;
    tx_buf[9] = crc8((const uint8_t*)tx_buf, 9);
    tx_len = 10;
    tx_idx = 0;
}

/* 4-byte GET_VERSION response: [PROTOCOL_VERSION, FW_MAJOR, FW_MINOR, FW_PATCH] */
static void build_version_response(void)
{
    tx_buf[0] = PROTOCOL_VERSION;
    tx_buf[1] = FW_VERSION_MAJOR;
    tx_buf[2] = FW_VERSION_MINOR;
    tx_buf[3] = FW_VERSION_PATCH;
    tx_len = 4;
    tx_idx = 0;
}


/* ═══════════════════════════════════════════════════════════════════════════
 * PWM  —  TIM1 CH2 on PA1
 * ═══════════════════════════════════════════════════════════════════════════ */

static void pwm_init(void)
{
    RCC->APB2PCENR |= RCC_APB2Periph_GPIOA | RCC_APB2Periph_TIM1;
    RCC->APB2PRSTR |=  RCC_APB2Periph_TIM1;
    RCC->APB2PRSTR &= ~RCC_APB2Periph_TIM1;

    GPIOA->CFGLR &= ~(0xF << (1 * 4));
    GPIOA->CFGLR |=  (0x9 << (1 * 4));   /* AF push-pull, 10 MHz */

    TIM1->PSC    = 47;
    TIM1->ATRLR  = 999;
    TIM1->CH2CVR = 0;
    TIM1->CHCTLR1 &= ~(TIM_OC2M | TIM_OC2PE);
    TIM1->CHCTLR1 |=  (6 << 12) | TIM_OC2PE;
    TIM1->SWEVGR  = TIM_UG;
    TIM1->CTLR1  |= TIM_ARPE | TIM_CEN;
}

static void pwm_start(uint16_t freq, uint8_t vol)
{
    if (freq == 0) { TIM1->BDTR &= ~TIM_MOE; return; }
    if (vol > 100) vol = 100;
    uint32_t arr = (TIM_CLK_HZ / (uint32_t)freq) - 1;
    if (arr > 0xFFFF) arr = 0xFFFF;
    TIM1->ATRLR  = (uint16_t)arr;
    TIM1->CH2CVR = (uint16_t)(((arr + 1) * vol) / 200);
    TIM1->CCER  |= TIM_CC2E;
    TIM1->SWEVGR = TIM_UG;
    TIM1->BDTR  |= TIM_MOE;
}

static void pwm_stop(void) { TIM1->BDTR &= ~TIM_MOE; }


/* ═══════════════════════════════════════════════════════════════════════════
 * TIM2  —  1 ms tick
 * ═══════════════════════════════════════════════════════════════════════════ */

static void tim2_init(void)
{
    RCC->APB1PCENR |= RCC_APB1Periph_TIM2;
    TIM2->PSC     = 47;
    TIM2->ATRLR   = 999;
    TIM2->DMAINTENR = TIM_IT_Update;
    TIM2->SWEVGR  = TIM_UG;
    TIM2->CTLR1  |= TIM_CEN;
    NVIC_EnableIRQ(TIM2_IRQn);
}

void TIM2_IRQHandler(void) __attribute__((interrupt));
void TIM2_IRQHandler(void) { TIM2->INTFR = 0; ms_tick++; }


/* ═══════════════════════════════════════════════════════════════════════════
 * I2C SLAVE  —  initialise at given address, or switch address at runtime
 * ═══════════════════════════════════════════════════════════════════════════ */

static void i2c_slave_init(uint8_t addr)
{
    RCC->APB2PCENR |= RCC_APB2Periph_GPIOC;
    RCC->APB1PCENR |= RCC_APB1Periph_I2C1;

    GPIOC->CFGLR &= ~(0xF << (1 * 4)); GPIOC->CFGLR |= (0xF << (1 * 4));
    GPIOC->CFGLR &= ~(0xF << (2 * 4)); GPIOC->CFGLR |= (0xF << (2 * 4));

    I2C1->CTLR1 |=  I2C_CTLR1_SWRST;
    I2C1->CTLR1 &= ~I2C_CTLR1_SWRST;

    I2C1->CTLR2  = 48;
    I2C1->CKCFGR = 240;
    I2C1->OADDR1 = ((uint16_t)addr << 1);

    I2C1->CTLR2 |= I2C_CTLR2_ITEVTEN | I2C_CTLR2_ITBUFEN | I2C_CTLR2_ITERREN;
    I2C1->CTLR1 |= I2C_CTLR1_ACK | I2C_CTLR1_PE;

    NVIC_EnableIRQ(I2C1_EV_IRQn);
    NVIC_EnableIRQ(I2C1_ER_IRQn);
}

/* Switch to a new I2C address without full re-init */
static void i2c_switch_addr(uint8_t addr)
{
    I2C1->CTLR1 &= ~I2C_CTLR1_PE;
    I2C1->OADDR1 = ((uint16_t)addr << 1);
    I2C1->CTLR1 |= I2C_CTLR1_ACK | I2C_CTLR1_PE;
}


/* ═══════════════════════════════════════════════════════════════════════════
 * I2C EVENT ISR
 * Behaviour depends on dev_state:
 *   DEV_ENUM_READY  — TRA: send 10-byte UID response
 *                   — RXNE: buffer bytes
 *                   — STOPF: if [0x1D, addr] → flag address switch
 *   DEV_ASSIGNED    — TRA: send 1-byte status
 *                   — RXNE: buffer command bytes
 *                   — STOPF: signal main loop to process command
 * ═══════════════════════════════════════════════════════════════════════════ */

void I2C1_EV_IRQHandler(void) __attribute__((interrupt));
void I2C1_EV_IRQHandler(void)
{
    uint32_t star1 = I2C1->STAR1;
    uint32_t star2 = I2C1->STAR2;   /* reading STAR2 clears ADDR flag */

    /* ── Address matched ──────────────────────────────────────── */
    if (star1 & I2C_STAR1_ADDR)
    {
        rx_len = 0;
        I2C1->CTLR1 |= I2C_CTLR1_ACK;

        if (star2 & I2C_STAR2_TRA)
        {
            /* Master is reading from us */
            if (dev_state == DEV_ENUM_READY)
            {
                build_uid_response();
                I2C1->DATAR = tx_buf[tx_idx++];
            }
            else if (version_pending)
            {
                /* Previous write was GET_VERSION → return the 4 version bytes */
                version_pending = 0;
                build_version_response();
                I2C1->DATAR = tx_buf[tx_idx++];
            }
            else
            {
                /* Status byte: 1=playing, 0=idle */
                tx_buf[0] = (play_state != PLAY_IDLE) ? 0x01 : 0x00;
                tx_len = 1; tx_idx = 1;
                I2C1->DATAR = tx_buf[0];
            }
        }
        return;
    }

    /* ── Byte received ────────────────────────────────────────── */
    if (star1 & I2C_STAR1_RXNE)
    {
        uint8_t b = (uint8_t)I2C1->DATAR;
        if (rx_len < RX_BUF_SIZE) rx_buf[rx_len++] = b;
        return;
    }

    /* ── Transmit buffer empty ────────────────────────────────── */
    if (star1 & I2C_STAR1_TXE)
    {
        I2C1->DATAR = (tx_idx < tx_len) ? tx_buf[tx_idx++] : 0x00;
        return;
    }

    /* ── Stop condition ───────────────────────────────────────── */
    if (star1 & I2C_STAR1_STOPF)
    {
        I2C1->CTLR1 |= I2C_CTLR1_PE;   /* clear STOPF */

        if (dev_state == DEV_ENUM_READY)
        {
            /* Check for ASSIGN command: [0x1D, new_address] */
            if (rx_len == 2 && rx_buf[0] == REG_ASSIGN_ADDR)
            {
                new_addr  = rx_buf[1];
                dev_state = DEV_ASSIGNING;  /* switch address in main loop */
            }
        }
        else if (dev_state == DEV_ASSIGNED)
        {
            /* GET_VERSION is handled entirely in the ISR: latch it so the next
             * read returns the version bytes. Don't route it to the main loop. */
            if (rx_len == 1 && rx_buf[0] == CMD_GET_VERSION)
                version_pending = 1;
            else if (rx_len > 0)
                cmd_ready = 1;
        }

        I2C1->CTLR1 |= I2C_CTLR1_ACK;
        return;
    }
}

void I2C1_ER_IRQHandler(void) __attribute__((interrupt));
void I2C1_ER_IRQHandler(void)
{
    I2C1->STAR1 &= ~(I2C_STAR1_BERR | I2C_STAR1_ARLO |
                     I2C_STAR1_AF   | I2C_STAR1_OVR);
    I2C1->CTLR1 |= I2C_CTLR1_ACK;
}


/* ═══════════════════════════════════════════════════════════════════════════
 * COMMAND PROCESSOR
 * ═══════════════════════════════════════════════════════════════════════════ */

static void process_command(void)
{
    uint8_t cmd = rx_buf[0];

    if (cmd == CMD_STOP)
    {
        pwm_stop();
        play_state = PLAY_IDLE;
    }
    else if (cmd == CMD_PLAY_NOTE && rx_len >= 5)
    {
        uint16_t freq = ((uint16_t)rx_buf[1] << 8) | rx_buf[2];
        uint8_t  dur  = rx_buf[3];
        uint8_t  vol  = rx_buf[4];
        pwm_stop();
        note_dur_ms   = (dur == 0) ? 0 : (uint32_t)dur * 100;
        note_start_ms = ms_tick;
        play_state    = PLAY_NOTE;
        pwm_start(freq, vol);
    }
    else if (cmd == CMD_PLAY_TUNE && rx_len >= 2)
    {
        uint8_t id = rx_buf[1];
        if (id == 0 || id > TUNE_COUNT) return;
        pwm_stop();
        tune_notes         = tune_table[id].notes;
        tune_len           = tune_table[id].count;
        tune_idx           = 0;
        tune_note_start_ms = ms_tick;
        play_state         = PLAY_TUNE;
        pwm_start(tune_notes[0].freq, 100);
    }
    else if (cmd == CMD_ENTER_BOOTLOADER)
    {
        /* OTA update requested: arm the handoff magic and warm-reset into the
         * bootloader (0x7E). NVIC_SystemReset() does not clear SRAM. */
        BL_MAGIC_CELL = BL_MAGIC_ENTER;
        NVIC_SystemReset();
    }
}


/* ═══════════════════════════════════════════════════════════════════════════
 * PLAYBACK UPDATER
 * ═══════════════════════════════════════════════════════════════════════════ */
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
int main(void)
{
    SystemInit();
    iwdg_init();          /* hardening C: hang -> warm reset -> stage-1 counts it */
    pwm_init();
    tim2_init();

    /* Calculate this module's unique backoff time from its hardware UID */
    calc_backoff();

    __enable_irq();

    /* Startup chime plays during backoff — confirms board is alive.
     * I2C is off during this time so the chime won't interfere. */
    rx_buf[0] = CMD_PLAY_TUNE; rx_buf[1] = 5;
    rx_len = 2;
    process_command();

    while (1)
    {
        uint32_t now = ms_tick;
        iwdg_kick();          /* every loop iteration; nothing here blocks > 2 s */

        /* ── State transitions ─────────────────────────────────── */

        if (dev_state == DEV_BOOT_WAITING && now >= backoff_ms)
        {
            /* Backoff complete — join the bus at staging address */
            enum_ready_start_ms = now;
            i2c_slave_init(ENUM_ADDR);
            dev_state = DEV_ENUM_READY;
        }

        /* Safety net: if not assigned within 200 ms, a collision likely
         * occurred. Re-backoff with short range (50–549 ms) so the
         * Conductor finds the module quickly on the next attempt. */
        if (dev_state == DEV_ENUM_READY && (now - enum_ready_start_ms) > 200)
        {
            I2C1->CTLR1 &= ~I2C_CTLR1_PE;
            backoff_ms = calc_rebackoff_ms();
            dev_state  = DEV_BOOT_WAITING;
        }

        if (dev_state == DEV_ASSIGNING)
        {
            /* Switch to Conductor-assigned address */
            i2c_switch_addr(new_addr);
            dev_state = DEV_ASSIGNED;
            BOOT_ATTEMPT_CELL = 0;   /* healthy: I2C works, enumeration done */
        }

        /* ── Normal operation ──────────────────────────────────── */

        if (dev_state == DEV_ASSIGNED)
        {
            if (cmd_ready)
            {
                cmd_ready = 0;
                process_command();
            }
            update_playback();
        }
        else
        {
            /* During BOOT_WAITING / ENUM_READY: still update playback
             * so the startup chime plays correctly */
            update_playback();
        }
    }
}

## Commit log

2026-05-08 Create hardware/kicad folder
2026-05-08 Upload schematics
2026-05-08 Add PCB images
2026-05-22 Initial working firmware & Python code for Pico
2026-05-29 Firmware v3.0: dynamic enumeration, non-blocking playback, tunes, volume
    - buzzer_firmware.c: complete rewrite (v1 → v3.0)
    - Dynamic I2C address via FNV-1a UID-based enumeration (no more 0x45)
    - Non-blocking playback using TIM2 1ms tick (replaces Delay_Ms blocking)
    - Volume control (PWM duty cycle, 0-100)
    - 5 preloaded tunes in flash (Nokia, Happy Birthday, Beep OK/Error, Startup)
    - PLAY_TUNE command (0x02) plays stored tune from CH32V003 flash
    - Status read returns 0x01=playing / 0x00=idle
    - Re-backoff collision recovery if not assigned within 200ms
    - noknok.py: new Conductor + NoknokBuzzer library (replaces buzzer.py)
    - Conductor class: enumerate(), by_uid(), c.buzzer[]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
    [buzzer_firmware.c]
2026-05-29 docs: comprehensive README rewrite + buzzer concept HTML
    - Full protocol documentation (PLAY NOTE, PLAY TUNE, STOP, status read)
    - Preloaded tune table with IDs and descriptions
    - Enumeration section explaining dynamic address assignment
    - Python API examples using Conductor + NoknokBuzzer
    - Hardware spec table with known issue (R1 VDD resistor)
    - Firmware build instructions and file index
    - Updated status: firmware v3.0 complete
    - Add docs/noknok-buzzer-concept.html — interactive protocol diagram
2026-05-29 noknok.py: add role management (load_roles, save_roles, setup_roles)
    Solves the problem of modules changing discovery index across reboots.
    Role names are bound to UIDs (permanent hardware IDs), not discovery order.
    - Conductor.load_roles(filename) — load noknok_roles.json, populate c.role{}
    - Conductor.save_roles(mapping) — save a role→module mapping to JSON
    - Conductor.setup_roles(filename) — interactive wizard: identifies each module
    (plays a beep for buzzers), prompts for role name, saves to file
    - Conductor._registry now stores uid_hex on every module object (_uid_hex)
    - Conductor.role{} initialized in __init__ so safe to access before load_roles
    Add noknok_setup_roles.py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
2026-05-29 Fix enumeration bug: correct FNV-1a backoff formula (v3.1)
    Bug: fnv_backoff(seed) computed h = seed XOR 2166136261 as starting value.
    When seed == 2166136261 (the FNV offset), h = 0, nullifying the FNV offset.
    Same-batch chips with uid[0] identical all started from the same h value,
    producing near-identical backoff times (10 ms apart for M1/M2 → collision).
    Fix in firmware:
    - Split into fnv_hash(h_init) and calc_backoff() / calc_rebackoff_ms()
    - calc_backoff() starts with h = 2166136261 (correct FNV-1a offset basis)
    - calc_rebackoff_ms() seeds with ms_tick, shorter range 50-549 ms
    Fix in noknok.py:
    - Increase no-response threshold from 500 ms to 3000 ms
    - Ensures Conductor waits long eno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
    [buzzer_firmware.c]
2026-05-29 docs: add Pico files section, filesystem write requirement, bump to v3.1
2026-06-01 fix: correct enumeration protocol comment (64-bit UID, 10-byte response)
    [buzzer_firmware.c]
2026-06-09 Firmware: bootloader-hosted build (I2C OTA)
    - Relink application at 0x1000 via app.ld (FLASH 0x1000/len 0x2C00,
    RAM 2032B so the bootloader handoff cell @0x200007F0 is protected)
    - Add 0xB0 ENTER_BOOTLOADER command: write magic 0x6E6B4231 to the
    handoff cell + NVIC_SystemReset() -> drops into the I2C bootloader
    - Makefile: LINKER_SCRIPT := app.ld, default target = build
    - All existing module logic unchanged
    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
2026-06-09 Add released firmware binary to firmware/bin
    Track the distributable offset-linked app image (flashed over I2C by the
    Pico). Adds a .gitignore exception so firmware/bin/*.bin is versioned while
    build artifacts elsewhere stay ignored.
2026-06-10 Remove noknok_enum_test.py from firmware/bin (moved to brain-Pico/software)
2026-06-10 Remove noknok_buzzer_test.py from firmware/bin (moved to brain-Pico/software)
2026-06-10 Remove Buzzer_OdeToTheJoy_Tune.py from firmware/bin (moved to brain-Pico/software)
2026-06-10 Remove noknok_setup_roles.py from firmware/bin (duplicate of brain-Pico/software)
2026-06-10 README: generic Pico files -> Conductor-level pointers (enumeration/roles); drop moved .py from Files table; fix noknok.py links to brain-Pico
2026-06-11 firmware v3.3.1: version-only bump for OTA auto-update test (DEV-6)
    No functional change. Bumps FW_VERSION_PATCH 0->1 so installed 3.3.0
    buzzers see an installed-vs-required delta and exercise the OTA
    auto-update path once the manifest is pointed at 3.3.1 (Sue).
    Rebuilt offset-linked bin (2928 B, vector@0x1000).
    [buzzer_firmware.c]
2026-06-23 chore: remove redundant hardware/kicad/.keep (folder now has content)
2026-07-05 mechanical: add housing.json (housing profile v1 scaffold)
    Footprint/mounting/connector-edges authoritative from Ecosystem PCB
    guideline; clearance heights + grille position marked TODO (unverified).
2026-07-06 mechanical: set buzzer clearances (top 3.0, bottom 3.0)
    Buzzer 8.5x8.7x3.0 mm is the only top-side component. Tallest bottom part
    is the side-entry JST-SH socket SM04B-SRSS-TB (2.9 mm) -> clearance_bottom
    3.0 incl. seating; cables exit horizontally through the bottom-gap notch.
2026-07-06 mechanical: verify buzzer positions from production files
    Production CSV + Edge_Cuts gerber (2026-04-08): board 20x20, buzzer centered
    (10,10). Fix connector Y for TOP/buzzer view - W socket near North (15.5),
    E near South (4.5) - was mirrored. Grille sized to the 8.5 mm buzzer.
    Noted KiCad top/bottom labelling quirk + current M2/castellated board rev.
2026-07-21 Buzzer hardware V2: fix R1 to 1R, add status LED + pogo flash pads, remove I2C pull-ups
    - Fixed R1 (VDD series) to 1R in the schematic itself - was documented as a known
    issue/bodge since V1 but never actually corrected in KiCad until now
    - Removed both castellated edge pads (old J3 I2C edge + J4 flash edge); I2C now
    via JST SH (J1/J2) only
    - New flash interface J3: noknok_FlashPads_I2C-module_1x3_M2.5 pogo pads
    (GND/SWIO/VCC) with keyed M2.5 hole
    - Added status LED D3 + R2 (2.2k) on PD1/SWIO, active-low, bootloader-driven
    - Removed on-board I2C pull-ups (host-only per ADR); buzzer-drive resistor
    renumbered R4 -> R3 (still 470R)
    - Added second mounting hole H1, diagonally opposite th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
    [Buzzer.kicad_pcb, Buzzer.kicad_sch, module-I2C-buzzer.kicad_pcb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]
2026-08-25 hardware: update schematic, rename BOM file, refresh schematic PDF and fix readme links
    [module-I2C-buzzer.kicad_sch, module-I2C-buzzer.xls, module-I2C-buzzer_BOM.xls]
2026-09-01 README: add trademark attribution for Qwiic and STEMMA QT
    The marks were already used adjectivally to state connector
    compatibility, which is permitted referential use - this adds the
    attribution and an explicit non-affiliation line, and corrects the
    capitalisation of STEMMA QT (Adafruit writes it uppercase).
2026-09-11 v3.4.0: DEV-31 hardening C - independent watchdog + boot-attempt handshake with stage-1
    Same change as LED Button v2.3: IWDG (~2 s) started after SystemInit and
    kicked every main-loop iteration; BOOT_ATTEMPT_CELL (0x200007F8) cleared the
    moment an I2C address is assigned. Under stage-1 this means a hanging app is
    booted three times and then parked for the Conductor to rescue; under the
    legacy bootloader the cell is unused RAM and the watchdog just restarts the
    app - harmless.
    Bench: pushed over I2C to the bench buzzer via Conductor.update_module(),
    re-enumerated at 0x08, reports v3.4.0. 2980 B.
    [buzzer_firmware.c]
2026-09-11 README: v3.4.0 — version strings + changelog (watchdog + boot-health handshake, DEV-31)
2026-09-11 v3.5.0: relink at 0x1400 (bootloader layout 2, stage-1 grows to 4 KB)
    No behaviour change. Built on the Pi from this source; the .bin is the layout-2 image. Not compatible with the legacy monolithic bootloader or a layout-1 stage-1 (DEV-31).
    [buzzer_firmware.c]
2026-09-11 Add firmware/index.json (current-firmware index)
    Declares the current firmware for this module in the same commit as the
    binary, so the version and the bytes cannot drift apart. Product manifests
    now carry only a floor (min); the brain reads this file to decide what to
    install, and requires_bootloader tells it when an image is NOT installable
    on the module in front of it.
    Spec: Ecosystem/software/firmware-index.md
    Registry: Ecosystem/software/modules.json
